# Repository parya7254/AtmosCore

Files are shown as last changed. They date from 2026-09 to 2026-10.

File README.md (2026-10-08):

# AtmosCore

AtmosCore is a smart ESP32-powered weather monitor! It consists of two modules that communicate wirelessly, one that collects weather data using sensors (which will typically be placed outside where weather data is sourced), and another that is connected to a screen and displays the data. It runs on battery that is charged by a solar panel.

# Key Features:
|Features|Model|
|-|-|
|Processor|ESPRESSIF ESP32-WROOM-32D-N8|
|Power Supply|Li-ion Battery (may change in future), chargeable by Solar Panel and by USB-C|
|Communication/Data Transfer|ESP-now|
|LDO|TPS63020DSJR buck boost|
|Battery Charger|TP4056|
|Temperature + Humidity + Pressure sensor|BME280|
|Light Sensor|BH1750FVI-TR|
|Temperature Sensors|KNTC0603/10KF3950|
|Radar Sensor|LD2140C

# Pictures of Outdoor Module!!
SCH_AtmosCore-Outdoor-Schematic_1-P1_2026-10-05
PCB_AtmosCore-Outdoor-PCB_2026-10-05
3D_AtmosCore-Outdoor-PCB_2026-10-05


# Pictures of Indoor Module!!
SCH_indoor-module_1-AtmosCore-Indoor-Schematic_2026-10-05
PCB_AtmosCore-Indoor-PCB_2026-10-05
3D_AtmosCore-Indoor-PCB_2026-10-05


## Note: This project was made with AI for researching stuff!

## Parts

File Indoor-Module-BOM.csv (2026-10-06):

No. | Quantity | Comment | Designator | Footprint | Value | Manufacturer Part | Manufacturer | Supplier Part | Supplier | LCSC Price | JLCPCB Price
1 | 5 | 100nF | C1,C2,C3,C12,C13 | C0603 | 100nF | CC0603JRX7R9BB104 | YAGEO(国巨) | C91183 | LCSC |  | 0.0032
2 | 2 | 10uF | C4,C8 | C0805 | 10uF | CL21A106KAYNNNE | SAMSUNG(三星) | C15850 | LCSC |  | 0.0098
3 | 2 | 1uF | C5,C11 | C0603 | 1uF | CL10A105KB8NNNC | SAMSUNG(三星) | C15849 | LCSC |  | 0.0022
4 | 3 | 100nF | C6,C7,C9 | C0402 | 100nF | CC0402KRX7R7BB104 | YAGEO(国巨) | C60474 | LCSC |  | 0.0008
5 | 1 | 1uF | C10 | C0402 | 1uF | TCC0402X5R105M6R3AT | CCTC(三环) | C2887021 | LCSC |  | 0.0007
6 | 1 | 22uF | C15 | C0603 | 22uF | CL10A226MP8NUNE | SAMSUNG(三星) | C86295 | LCSC |  | 0.0065
7 | 2 | SS14 | D1,D3 | SMA_L4.3-W2.6-LS5.0-RD |  | SS14 | YONGYUTAI(永裕泰) | C47147601 | LCSC |  | 0.0019
8 | 2 | Test-Point | GND,VBAT | Test-Point-0.5mm |  |  |  |  |  | 0.9351
9 | 1 | 2.54-1*14P母 | H1 | HDR-TH_14P-P2.54-V-F-1 |  | 2.54-1*14P母 | BOOMELE(博穆精密) | C52711 | LCSC |  | 0.0216
10 | 1 | YLED0603R | LED1 | LED0603-FD |  | YLED0603R | YONGYUTAI(永裕泰) | C19171390 | LCSC |  | 0.001
11 | 2 | BSS138 | Q1,Q2 | SOT-23-3_L2.9-W1.3-P1.90-LS2.4-BR-1 |  | BSS138 | KUU | C3015220 | LCSC |  | 0.003
12 | 3 | 1kΩ | R1,R2,R7 | R0402 | 1kΩ | FRC0402J102 TS | FOJAN(富捷) | C2906899 | LCSC |  | 0.0003
13 | 2 | 10kΩ | R3,R4 | R0402 | 10kΩ | FRC0402F1002TS | FOJAN(富捷) | C2906861 | LCSC |  | 0.0004
14 | 2 | 10kΩ | R5,R13 | R0603 | 10kΩ | RC0603FR-0710KL | YAGEO(国巨) | C98220 | LCSC |  | 0.0006
15 | 1 | 1.2kΩ | R6 | R0603 | 1.2kΩ | 0603WAF1201T5E | UNI-ROYAL(厚声) | C22765 | LCSC |  | 0.0006
16 | 2 | 5.1kΩ | R8,R9 | R0603 | 5.1kΩ | 0603WAF5101T5E | UNI-ROYAL(厚声) | C23186 | LCSC |  | 0.0003
17 | 2 | 4.7kΩ | R10,R11 | R0603 | 4.7kΩ | 0603WAF4701T5E | UNI-ROYAL(厚声) | C23162 | LCSC |  | 0.0005
18 | 2 | 470kΩ | R12,R14 | R0603 | 470kΩ | 0603WAF4703T5E | UNI-ROYAL(厚声) | C23178 | LCSC |  | 0.0005
19 | 1 | HLK-LD2410C-P | SM1 | SENSOR-TH_HLK-LD2410C-P |  | HLK-LD2410C-P | HI-LINK(海凌科) | C19723500 | LCSC |  | 0.8185
20 | 2 | HX 3x4x2-2P-1.6N TACTILE SWITCH | SW1,SW2 | KEY-SMD_L4.0-W3.0-LS4.9-1 |  | HX 3x4x2-2P-1.6N TACTILE SWITCH | hanxia(韩下) | C49234124 | LCSC |  | 0.0038
21 | 1 | 2.4GHz | U1 | WIFI-SMD_ESP32-WROOM-32E | 2.4GHz | ESP32-WROOM-32E-N8 | ESPRESSIF(乐鑫) | C701342 | LCSC |  | 0.6826
22 | 1 | MCP1700-3302E/TO | U2 | TO-92-3_L5.1-W4.1-P1.27-L |  | MCP1700-3302E/TO | MICROCHIP(美国微芯) | C511277 | LCSC |  | 0.1621
23 | 1 | YLED0603G | U3 | LED0603-FD |  | YLED0603G | YONGYUTAI(永裕泰) | C19273151 | LCSC |  | 0.001
24 | 1 | BME280 | U4 | LGA-8_BME280_BL |  | BME280 | Bosch(博世) | C92489 | LCSC |  | 1.1485
25 | 1 | CH340C | U5 | SOP-16_L10.0-W3.9-P1.27-LS6.0-BL |  | CH340C | WCH(南京沁恒) | C84681 | LCSC |  | 0.091
26 | 1 | K6-6277D-02A | U6 | SW-TH_TM-007-D1-A-03 |  | K6-6277D-02A | 韩国韩荣 | C5337090 | LCSC |  | 0.2208
27 | 1 | TP4056 | U7 | ESOP-8_L4.9-W3.9-P1.27-LS6.0-BL-EP |  | TP4056 | TECH PUBLIC(台舟) | C5311018 | LCSC |  | 0.0144
28 | 1 | MC-403L68-Z20 | USB1 | USB-C-SMD_MC-403L68-Z20 |  | MC-403L68-Z20 | HANBO(汉博) | C47326497 | LCSC |  | 0.0105

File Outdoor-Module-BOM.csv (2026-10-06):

No. | Quantity | Comment | Designator | Footprint | Value | Manufacturer Part | Manufacturer | Supplier Part | Supplier | LCSC Price | JLCPCB Price
1 | 2 | Test-Point | BAT+,GND | Test-Point-0.5mm |  |  |  |  |  | 0.6791
2 | 3 | 10uF | C1,C8,C19 | C0603 | 10uF | CL10A106MA8NRNC | SAMSUNG(三星) | C96446 | LCSC |  | 0.0114
3 | 5 | 100nF | C2,C3,C12,C13,C14 | C0603 | 100nF | 0603B104M500NT | FH(风华) | C286510 | LCSC |  | 0.0008
4 | 1 | 10uF | C4 | C0805 | 10uF | CL21A106KAYNNNE | SAMSUNG(三星) | C15850 | LCSC |  | 0.0098
5 | 2 | 1uF | C5,C10 | C0402 | 1uF | TCC0402X5R105M6R3AT | CCTC(三环) | C2887021 | LCSC |  | 0.0007
6 | 3 | 100nF | C6,C7,C9 | C0402 | 100nF | CC0402KRX7R7BB104 | YAGEO(国巨) | C60474 | LCSC |  | 0.0008
7 | 4 | 22uF | C11,C16,C17,C18 | C0603 | 22uF | CL10A226MP8NUNE | SAMSUNG(三星) | C86295 | LCSC |  | 0.0065
8 | 1 | 22uF | C15 | C0805 | 22uF | CL21A226MAQNNNE | SAMSUNG(三星) | C45783 | LCSC |  | 0.0332
9 | 2 | SS14 | D1,D2 | SMA_L4.3-W2.6-LS5.0-RD |  | SS14 | YONGYUTAI(永裕泰) | C47147601 | LCSC |  | 0.0019
10 | 2 | ESD5Z5V0 | D3,D4 | SOD-523_L1.2-W0.8-LS1.6-RD |  | ESD5Z5V0 | JSMSEMI(杰盛微) | C917016 | LCSC |  | 0.0041
11 | 1 | DC-005-20 | DC1 | DC-IN-TH_DC-005-20 |  | DC-005-20 | JXTCONN(聚兴泰) | C52125075 | LCSC |  | 0.0265
12 | 1 | HX PH254-01-04-Z-L11.5 straight pin header | H1 | HDR-TH_4P-HX-PH254-01-04-Z-L11.5 |  | HX PH254-01-04-Z-L11.5 straight pin header | hanxia(韩下) | C52016392 | LCSC |  | 0.005
13 | 1 | 1uH | L1 | L0603 | 1uH | FHW0603UF1R0JST | FH(风华) | C127458 | LCSC |  | 0.0069
14 | 2 | BSS138 | Q1,Q2 | SOT-23-3_L2.9-W1.3-P1.90-LS2.4-BR-1 |  | BSS138 | KUU | C3015220 | LCSC |  | 0.003
15 | 2 | 1MΩ | R1,R2 | R0603 | 1MΩ | 0603WAF1004T5E | UNI-ROYAL(厚声) | C22935 | LCSC |  | 0.0003
16 | 1 | 180kΩ | R3 | R0603 | 180kΩ | 0603WAF1803T5E | UNI-ROYAL(厚声) | C22827 | LCSC |  | 0.0003
17 | 3 | 10kΩ | R4,R5,R13 | R0603 | 10kΩ | RC0603FR-0710KL | YAGEO(国巨) | C98220 | LCSC |  | 0.0006
18 | 1 | 1.2kΩ | R6 | R0603 | 1.2kΩ | 0603WAF1201T5E | UNI-ROYAL(厚声) | C22765 | LCSC |  | 0.0006
19 | 1 | 1kΩ | R7 | R0805 | 1kΩ | 0805W8F1001T5E | UNI-ROYAL(厚声) | C17513 | LCSC |  | 0.0007
20 | 2 | 5.1kΩ | R8,R9 | R0603 | 5.1kΩ | 0603WAF5101T5E | UNI-ROYAL(厚声) | C23186 | LCSC |  | 0.0003
21 | 2 | 4.7kΩ | R10,R11 | R0603 | 4.7kΩ | 0603WAF4701T5E | UNI-ROYAL(厚声) | C23162 | LCSC |  | 0.0005
22 | 2 | 10kΩ | R12,R14 | R0402 | 10kΩ | FRC0402F1002TS | FOJAN(富捷) | C2906861 | LCSC |  | 0.0004
23 | 2 | 470kΩ | R15,R16 | R0603 | 470kΩ | 0603WAF4703T5E | UNI-ROYAL(厚声) | C23178 | LCSC |  | 0.0005
24 | 2 | HX 3x4x2-2P-1.6N TACTILE SWITCH | SW1,SW2 | KEY-SMD_L4.0-W3.0-LS4.9-1 |  | HX 3x4x2-2P-1.6N TACTILE SWITCH | hanxia(韩下) | C49234124 | LCSC |  | 0.0038
25 | 1 | 2.4GHz | U1 | WIFI-SMD_ESP32-WROOM-32E | 2.4GHz | ESP32-WROOM-32E-N8 | ESPRESSIF(乐鑫) | C701342 | LCSC |  | 0.6826
26 | 1 | BME280 | U2 | LGA-8_BME280_BL |  | BME280 | Bosch(博世) | C92489 | LCSC |  | 1.1485
27 | 1 | BH1750FVI-TR | U3 | WSOF-6_L2.6-W1.6-P0.50-TL-EP |  | BH1750FVI-TR | ROHM(罗姆) | C78960 | LCSC |  | 0.1414
28 | 1 | CH340C | U5 | SOP-16_L10.0-W3.9-P1.27-LS6.0-BL |  | CH340C | WCH(南京沁恒) | C84681 | LCSC |  | 0.091
29 | 1 | TPS63020DSJR | U6 | VSON-14_L4.0-W3.0-P0.50-BL-EP_TI_DSJ |  | TPS63020DSJR | TI(德州仪器) | C15483 | LCSC |  | 0.1367
30 | 1 | TP4056 | U7 | ESOP-8_L4.9-W3.9-P1.27-LS6.0-BL-EP |  | TP4056 | TECH PUBLIC(台舟) | C5311018 | LCSC |  | 0.0144
31 | 1 | MC-403L68-Z20 | USB1 | USB-C-SMD_MC-403L68-Z20 |  | MC-403L68-Z20 | HANBO(汉博) | C47326497 | LCSC |  | 0.0105

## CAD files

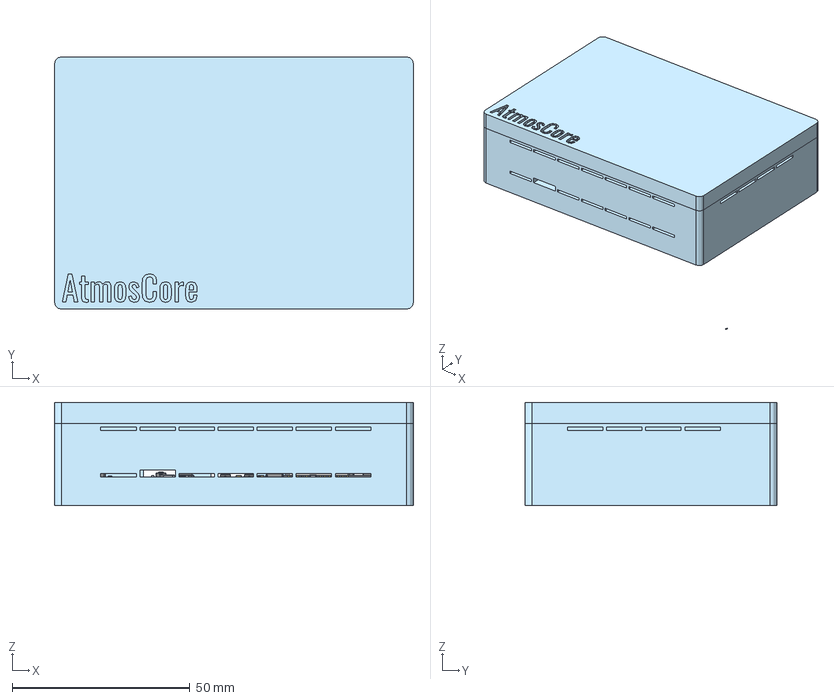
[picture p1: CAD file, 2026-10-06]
CAD/Outdoor-Module/Outdoor Module Assembly.step
101.0 x 71.0 x 67.4 mm
LGA-8_BME280_BL~LGA-8_L2.5-W2.5-H0.9-P0.65~9fjv__Í¹Ì¨ -ï¿½ï¿½ï¿½ï¿½6
SMA_L4.3-W2.6-LS5.0-RD~SMA_L4.3-W2.6-LS5.0-RD~qoYE__Í¹Ì¨ -ï¿½ï¿½ï¿½ï¿½3 x 2
C0603~C0603_L1.6-W0.8-H0.8~1LH6__Í¹Ì¨-ï¿½ ï¿½ï¿½ï¿½3 x 14
C0603~C0402_L1.0-W0.5-H0.5~J49s__Í¹Ì¨-ï¿½ ï¿½ï¿½ï¿½3 x 5
R0603~R0603~o3r0__ï¿½ï¿½ï ¿½ï¿½2 x 13
R0603~R0603~o3r0__Í¹Ì¨-ï¿½ ï¿½ï¿½ï¿½3 x 13
R0603~R0603~o3r0__Í¹Ì¨-ï¿½ ï¿½ï¿½ï¿½2 x 13
R0603~R0603~o3r0__ï¿½Ð³ï¿½-ï¿ ½ï¿½ï¿½ï¿½2 x 13
KEY-SMD_L4.0-W3.0-LS4.9-1~KEY-SMD_L4.0-W3.0-LS4.9-1~vl9t__Í¹Ì ¨-ï¿½ï¿½ï¿½ï¿½8 x 2
SOP-16_L10.0-W3.9-P1.27-LS6.0-BL~SOP-16_L9.9-W3.9-H1.5-LS6.0-P1.27~sX X8
DC-IN-TH_DC-005-20~DC-IN-TH_DC-005-20~lUyZ__ï¿½ï¿ ½ï¿½ï¿½1
DC-IN-TH_DC-005-20~DC-IN-TH_DC-005-20~lUyZ__Ô²ï¿½ ï¿½3
DC-IN-TH_DC-005-20~DC-IN-TH_DC-005-20~lUyZ__Í¹Ì¨-ï ¿½ï¿½ï¿½ï¿½5
SOD-523_L1.2-W0.8-LS1.6-RD~SOD-523_L1.2-W0.8-H0.7-LS1.6~dDVy__ï¿ ½ï¿½0.15-ï¿½ï¿½0.3-ï¿½ ï¿½0.3Ö±ï¿½ï¿½ï¿½ ï¿½ - ï¿½ï¿½ï¿½ï¿ ½-1-solid1 x 2
SOD-523_L1.2-W0.8-LS1.6-RD~SOD-523_L1.2-W0.8-H0.7-LS1.6~dDVy__ï¿ ½ï¿½0.15-ï¿½ï¿½0.3-ï¿½ ï¿½0.3Ö±ï¿½ï¿½ï¿½ ï¿½ - ï¿½ï¿½ï¿½ï¿ ½-2-solid1 x 2
SOD-523_L1.2-W0.8-LS1.6-RD~SOD-523_L1.2-W0.8-H0.7-LS1.6~dDVy__Í¹ Ì¨-ï¿½ï¿½ï¿½ï¿½ 2 x 2
WSOF-6_L2.6-W1.6-P0.50-TL-EP~WSOF-6_L1.6-W2.6-H0.8-P0.50~j2RC__Í¹ Ì¨-ï¿½ï¿½ï¿½ï¿½ 4
WSOF-6_L2.6-W1.6-P0.50-TL-EP~WSOF-6_L1.6-W2.6-H0.8-P0.50~j2RC__Í¹ Ì¨-ï¿½ï¿½ï¿½ï¿½ 2[2]
WSOF-6_L2.6-W1.6-P0.50-TL-EP~WSOF-6_L1.6-W2.6-H0.8-P0.50~j2RC__Í¹ Ì¨-ï¿½ï¿½ï¿½ï¿½ 2[3]
WSOF-6_L2.6-W1.6-P0.50-TL-EP~WSOF-6_L1.6-W2.6-H0.8-P0.50~j2RC__Í¹ Ì¨-ï¿½ï¿½ï¿½ï¿½ 2[1]
HDR-TH_4P-HX-PH254-01-04-Z-L11.5~HDR-TH_4P-HX-PH254-01-04-Z-L11.5~maJ 2__ï¿½ï¿½ï¿½ï¿½2
HDR-TH_4P-HX-PH254-01-04-Z-L11.5~HDR-TH_4P-HX-PH254-01-04-Z-L11.5~maJ 2__ï¿½ï¿½ï¿½ï¿½(ï¿ ½ï¿½ï¿½ï¿½)2[1]
HDR-TH_4P-HX-PH254-01-04-Z-L11.5~HDR-TH_4P-HX-PH254-01-04-Z-L11.5~maJ 2__Í¹Ì¨-ï¿½ï¿½ï¿½ï ¿½4
HDR-TH_4P-HX-PH254-01-04-Z-L11.5~HDR-TH_4P-HX-PH254-01-04-Z-L11.5~maJ 2__ï¿½ï¿½ï¿½ï¿½(ï¿ ½ï¿½ï¿½ï¿½)2[2]
HDR-TH_4P-HX-PH254-01-04-Z-L11.5~HDR-TH_4P-HX-PH254-01-04-Z-L11.5~maJ 2__ï¿½ï¿½ï¿½ï¿½(ï¿ ½ï¿½ï¿½ï¿½)2[3]
HDR-TH_4P-HX-PH254-01-04-Z-L11.5~HDR-TH_4P-HX-PH254-01-04-Z-L11.5~maJ 2__ï¿½ï¿½ï¿½ï¿½(ï¿ ½ï¿½ï¿½ï¿½)1[2]
HDR-TH_4P-HX-PH254-01-04-Z-L11.5~HDR-TH_4P-HX-PH254-01-04-Z-L11.5~maJ 2__ï¿½ï¿½ï¿½ï¿½(ï¿ ½ï¿½ï¿½ï¿½)1[1]
HDR-TH_4P-HX-PH254-01-04-Z-L11.5~HDR-TH_4P-HX-PH254-01-04-Z-L11.5~maJ 2__ï¿½Æ¶ï¿½ï¿½ï¿½ 1[1]
WIFI-SMD_ESP32-WROOM-32E~WIFI-SMD_L25.5-W18.0-H3.1-ESP32-WROOM-32E~HH XW__Í¹Ì¨-ï¿½ï¿½ï¿½ ï¿½4[10]
WIFI-SMD_ESP32-WROOM-32E~WIFI-SMD_L25.5-W18.0-H3.1-ESP32-WROOM-32E~HH XW__Í¹Ì¨-ï¿½ï¿½ï¿½ ï¿½4[3]
WIFI-SMD_ESP32-WROOM-32E~WIFI-SMD_L25.5-W18.0-H3.1-ESP32-WROOM-32E~HH XW__Í¹Ì¨-ï¿½ï¿½ï¿½ ï¿½4[13]
WIFI-SMD_ESP32-WROOM-32E~WIFI-SMD_L25.5-W18.0-H3.1-ESP32-WROOM-32E~HH XW__Í¹Ì¨-ï¿½ï¿½ï¿½ ï¿½3
WIFI-SMD_ESP32-WROOM-32E~WIFI-SMD_L25.5-W18.0-H3.1-ESP32-WROOM-32E~HH XW__Í¹Ì¨-ï¿½ï¿½ï¿½ ï¿½4[9]
WIFI-SMD_ESP32-WROOM-32E~WIFI-SMD_L25.5-W18.0-H3.1-ESP32-WROOM-32E~HH XW__Í¹Ì¨-ï¿½ï¿½ï¿½ ï¿½4[7]
WIFI-SMD_ESP32-WROOM-32E~WIFI-SMD_L25.5-W18.0-H3.1-ESP32-WROOM-32E~HH XW__Í¹Ì¨-ï¿½ï¿½ï¿½ ï¿½4[2]
WIFI-SMD_ESP32-WROOM-32E~WIFI-SMD_L25.5-W18.0-H3.1-ESP32-WROOM-32E~HH XW__Í¹Ì¨-ï¿½ï¿½ï¿½ ï¿½4[8]
WIFI-SMD_ESP32-WROOM-32E~WIFI-SMD_L25.5-W18.0-H3.1-ESP32-WROOM-32E~HH XW__Í¹Ì¨-ï¿½ï¿½ï¿½ ï¿½4[6]
WIFI-SMD_ESP32-WROOM-32E~WIFI-SMD_L25.5-W18.0-H3.1-ESP32-WROOM-32E~HH XW__Í¹Ì¨-ï¿½ï¿½ï¿½ ï¿½4[1]
WIFI-SMD_ESP32-WROOM-32E~WIFI-SMD_L25.5-W18.0-H3.1-ESP32-WROOM-32E~HH XW__Í¹Ì¨-ï¿½ï¿½ï¿½ ï¿½4[5]
WIFI-SMD_ESP32-WROOM-32E~WIFI-SMD_L25.5-W18.0-H3.1-ESP32-WROOM-32E~HH XW__Í¹Ì¨-ï¿½ï¿½ï¿½ ï¿½4[12]
WIFI-SMD_ESP32-WROOM-32E~WIFI-SMD_L25.5-W18.0-H3.1-ESP32-WROOM-32E~HH XW__Í¹Ì¨-ï¿½ï¿½ï¿½ ï¿½4[4]
WIFI-SMD_ESP32-WROOM-32E~WIFI-SMD_L25.5-W18.0-H3.1-ESP32-WROOM-32E~HH XW__Í¹Ì¨-ï¿½ï¿½ï¿½ ï¿½4[11]
Board~sXX8
SOT-23-3_L2.9-W1.3-P1.90-LS2.4-BR-1~SOT-23-3P_L2.9-W1.3-H1.0-LS2.4-P0. 95~eoEG__Í¹Ì¨-ï¿½ï¿½ï¿ ½ï¿½1[2] x 2
SOT-23-3_L2.9-W1.3-P1.90-LS2.4-BR-1~SOT-23-3P_L2.9-W1.3-H1.0-LS2.4-P0. 95~eoEG__Í¹Ì¨-ï¿½ï¿½ï¿ ½ï¿½1[12] x 2
SOT-23-3_L2.9-W1.3-P1.90-LS2.4-BR-1~SOT-23-3P_L2.9-W1.3-H1.0-LS2.4-P0. 95~eoEG__SOT-23-3P_L2.9-W1.3-H1.-LS2.4-P0.95ï¿½ï¿½ ï¿½ï¿½-1-solid1 x 2
SOT-23-3_L2.9-W1.3-P1.90-LS2.4-BR-1~SOT-23-3P_L2.9-W1.3-H1.0-LS2.4-P0. 95~eoEG__Í¹Ì¨-ï¿½ï¿½ï¿ ½ï¿½1[11] x 2
SOT-23-3_L2.9-W1.3-P1.90-LS2.4-BR-1~SOT-23-3P_L2.9-W1.3-H1.0-LS2.4-P0. 95~eoEG__Í¹Ì¨-ï¿½ï¿½ï¿ ½ï¿½1[9] x 2
SOT-23-3_L2.9-W1.3-P1.90-LS2.4-BR-1~SOT-23-3P_L2.9-W1.3-H1.0-LS2.4-P0. 95~eoEG__Í¹Ì¨-ï¿½ï¿½ï¿ ½ï¿½1[6] x 2
SOT-23-3_L2.9-W1.3-P1.90-LS2.4-BR-1~SOT-23-3P_L2.9-W1.3-H1.0-LS2.4-P0. 95~eoEG__Í¹Ì¨-ï¿½ï¿½ï¿ ½ï¿½1[10] x 2
SOT-23-3_L2.9-W1.3-P1.90-LS2.4-BR-1~SOT-23-3P_L2.9-W1.3-H1.0-LS2.4-P0. 95~eoEG__Í¹Ì¨-ï¿½ï¿½ï¿ ½ï¿½1[13] x 2
SOT-23-3_L2.9-W1.3-P1.90-LS2.4-BR-1~SOT-23-3P_L2.9-W1.3-H1.0-LS2.4-P0. 95~eoEG__ï¿½ï¿½0.1-ï¿½ï¿½ 0.4-ï¿½ï¿½0.6-ï¿½ï¿½0. 5ï¿½ï¿½ï¿½ï¿½-5-solid1 x 2
SOT-23-3_L2.9-W1.3-P1.90-LS2.4-BR-1~SOT-23-3P_L2.9-W1.3-H1.0-LS2.4-P0. 95~eoEG__Í¹Ì¨-ï¿½ï¿½ï¿ ½ï¿½1[1] x 2
SOT-23-3_L2.9-W1.3-P1.90-LS2.4-BR-1~SOT-23-3P_L2.9-W1.3-H1.0-LS2.4-P0. 95~eoEG__Í¹Ì¨-ï¿½ï¿½ï¿ ½ï¿½1[8] x 2
SOT-23-3_L2.9-W1.3-P1.90-LS2.4-BR-1~SOT-23-3P_L2.9-W1.3-H1.0-LS2.4-P0. 95~eoEG__Í¹Ì¨-ï¿½ï¿½ï¿ ½ï¿½1[3] x 2
SOT-23-3_L2.9-W1.3-P1.90-LS2.4-BR-1~SOT-23-3P_L2.9-W1.3-H1.0-LS2.4-P0. 95~eoEG__Í¹Ì¨-ï¿½ï¿½ï¿ ½ï¿½1[5] x 2
SOT-23-3_L2.9-W1.3-P1.90-LS2.4-BR-1~SOT-23-3P_L2.9-W1.3-H1.0-LS2.4-P0. 95~eoEG__Í¹Ì¨-ï¿½ï¿½ï¿ ½ï¿½1[7] x 2
SOT-23-3_L2.9-W1.3-P1.90-LS2.4-BR-1~SOT-23-3P_L2.9-W1.3-H1.0-LS2.4-P0. 95~eoEG__ï¿½ï¿½0.1-ï¿½ï¿½ 0.4-ï¿½ï¿½0.6-ï¿½ï¿½0. 5ï¿½ï¿½ï¿½ï¿½-7-solid1 x 2
SOT-23-3_L2.9-W1.3-P1.90-LS2.4-BR-1~SOT-23-3P_L2.9-W1.3-H1.0-LS2.4-P0. 95~eoEG__ï¿½ï¿½0.1-ï¿½ï¿½ 0.4-ï¿½ï¿½0.6-ï¿½ï¿½0. 5ï¿½ï¿½ï¿½ï¿½-1-solid1 x 2
SOT-23-3_L2.9-W1.3-P1.90-LS2.4-BR-1~SOT-23-3P_L2.9-W1.3-H1.0-LS2.4-P0. 95~eoEG__Í¹Ì¨-ï¿½ï¿½ï¿ ½ï¿½1[4] x 2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

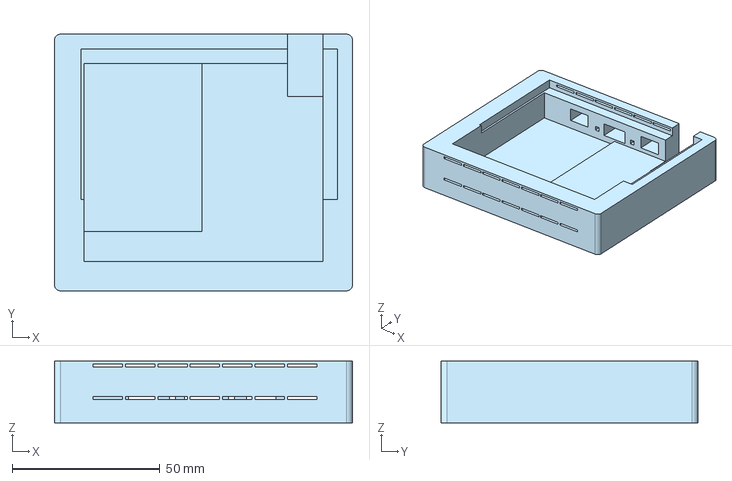
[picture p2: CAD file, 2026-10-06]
CAD/Indoor-Module/Indoor-Bottom.step
101.0 x 87.0 x 21.0 mm

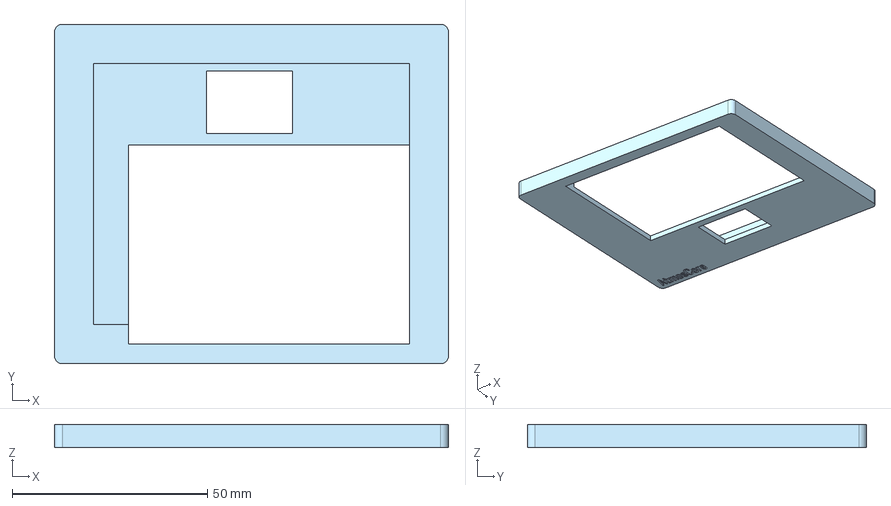
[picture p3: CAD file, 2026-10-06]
CAD/Indoor-Module/Indoor-Top.step
101.0 x 87.0 x 6.00 mm

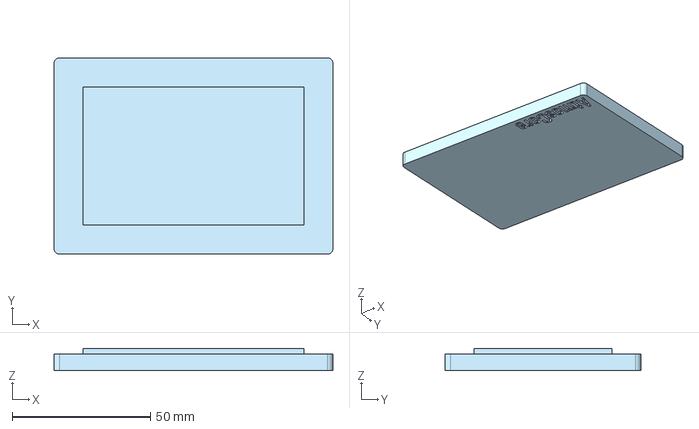
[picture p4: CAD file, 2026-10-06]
CAD/Outdoor-Module/Outdoor-Top.step
101.0 x 71.0 x 8.00 mm

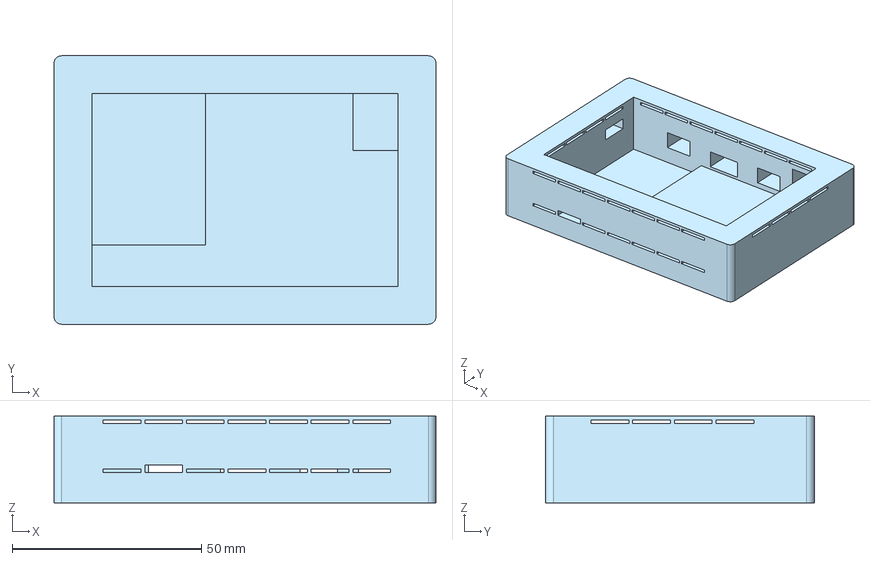
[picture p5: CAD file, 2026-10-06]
CAD/Outdoor-Module/Outdoor-Bottom.step
101.0 x 71.0 x 23.0 mm

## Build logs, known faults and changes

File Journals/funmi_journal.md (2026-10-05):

**17th and 18th September** 
So, we have our project decided on. We're gonna be working on a smart ESP32-powered weather station that contains two modules that communicate wirelessly, one that collects weather data using sensors (will typically be placed outside where weather data is sourced), and another that is connected to a screen and displays this data. It runs on battery and charged by a solar panel. More details will be added soon.

I searched, added, and wired components for our weather tracker and display system including the processor chip (espressif esp32 wroom), ldo, battery points for the solar panel and battery, and a battery charger for the battery. I also added some of the sensors for the weather. Our device will track temperature, humidity, pressure, wind speed, wind direction, rain, and light/UV.

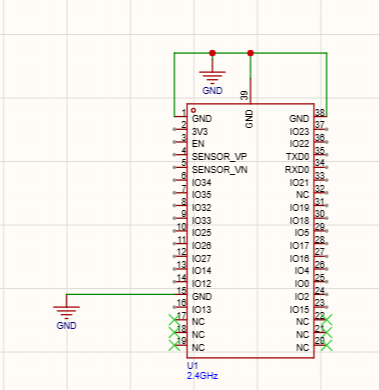
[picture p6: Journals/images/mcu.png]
mcu


power

We found suitable modules for temp, pressure, humidity and UV light, but we're still gonna finalize for wind speed, wind direction, and rain (amount of rain fall).

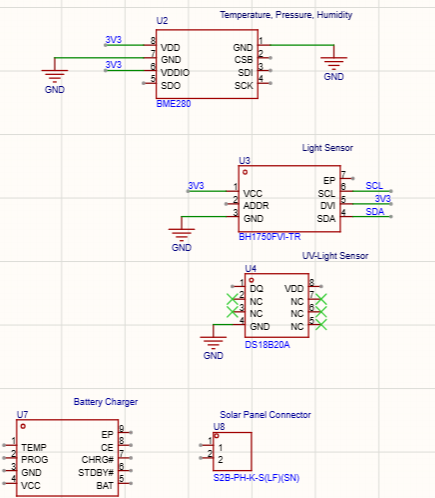
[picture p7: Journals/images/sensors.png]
sensors


Timelapse: https://lapse.hackclub.com/timelapse/0soD5C5SFuWm

---

**18th September midnight**

I started wiring the ldo. I wired input voltage, switching nodes, and power with necessary caps using the datasheet. I also wired the gpio pins on the processor.

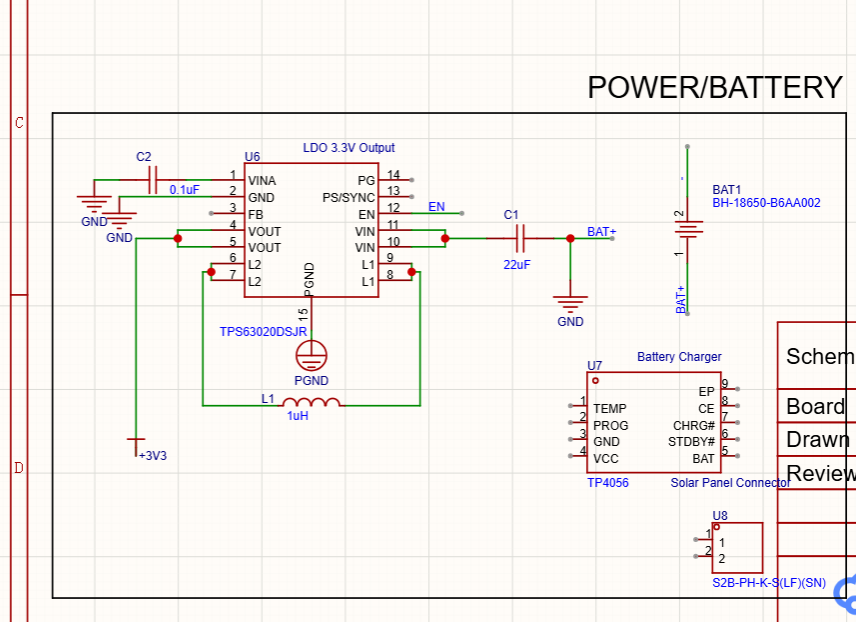
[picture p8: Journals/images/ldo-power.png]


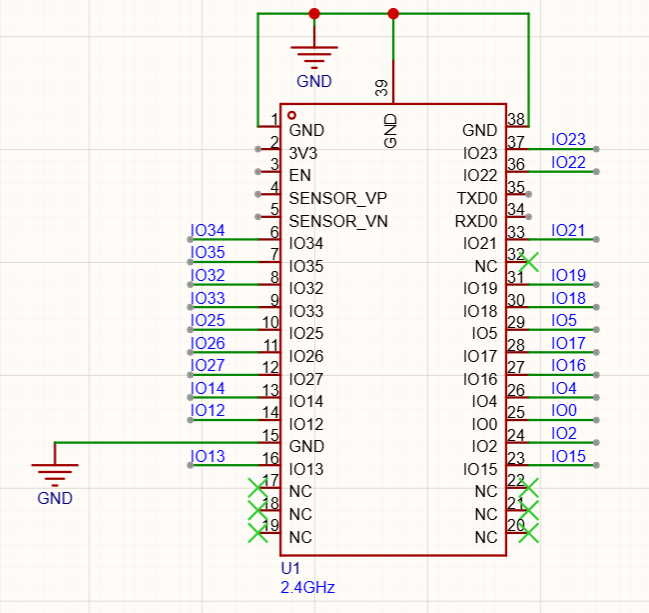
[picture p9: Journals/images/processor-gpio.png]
gpio


Timelapse: https://lapse.hackclub.com/timelapse/47Nh-5HsW0Z_

---

**19th September**

I finished wiring up the ldo. I wired up enable, power saving, and some other pins. We're gonna use the Adafruit 6V 2W solar panel that has a barrel jack connector, so I added the jack socket (or whatever its calld) that will connect to the jack of the solar panel. I also started wiring the TP4056 to the battery and the solar.

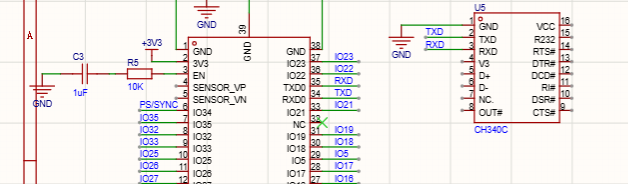
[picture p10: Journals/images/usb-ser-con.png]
usb-serial-connector


sensors

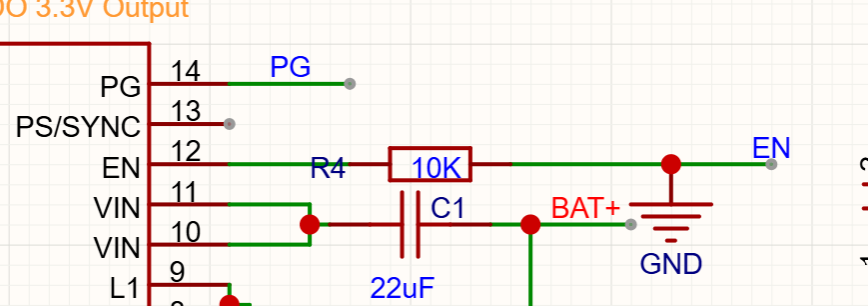
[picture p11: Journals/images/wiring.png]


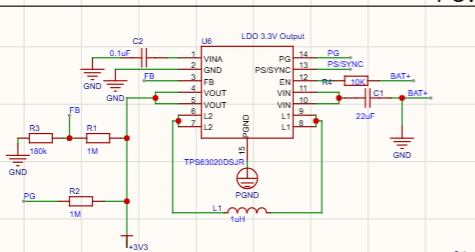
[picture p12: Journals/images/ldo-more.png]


Timelapse: https://lapse.hackclub.com/timelapse/MDIkPO2Eiles
Timelapse 2: https://lapse.hackclub.com/timelapse/ODEb5UjX_YcE

---

**19th September evening**

We decided to not connect status LEDs for the battery charger (CHRG and STDBY), but instead connect them to two separate GPIOs and have it display in our second module when the battery is charging or full. If we happen to run out of GPIOs, which I don't think we will, I'll wire both statuses to one pin.

Anyways, I finished wiring up the battery charger and fixed a lot of bugs in my wiring (for example, shorting VIN, and some other pins). I think there might still be some things I might have wired wrongly, which I'll fix tomorrow.

I also added and wired an NTC temp sensor to avoid charging the battery while it is overheated.

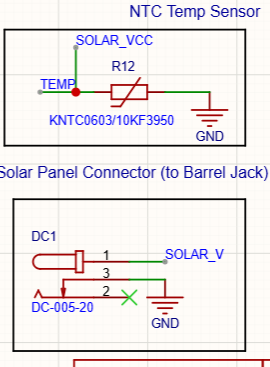
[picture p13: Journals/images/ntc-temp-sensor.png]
ntc-temp-sensor


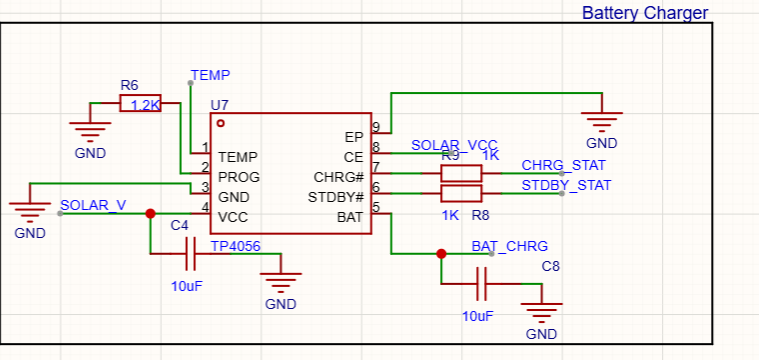
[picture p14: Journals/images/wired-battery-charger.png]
wired-batt-charger


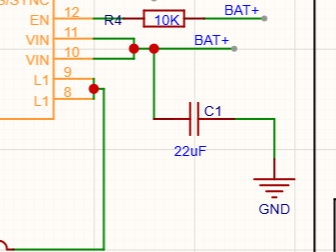
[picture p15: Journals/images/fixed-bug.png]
bug-fix


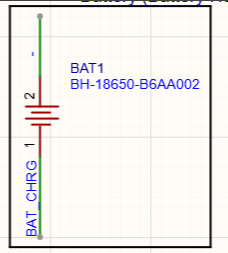
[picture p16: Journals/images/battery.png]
batt


Timelapse: https://lapse.hackclub.com/timelapse/Cc5SS9TyneUY

---

**20th September**

Rounding up wiring for the outdoor-module - I added decoupling capacitors for the battery charger and esp32..

I also added a schottky diode to prevent back charge to the solar panel. For the charging status pins, we decided we would enable pullup internally with code instead. and we removed the resistors I had added to the pins. i also fixed a couple of other wiring mistakes

Then, I began the indoor-module schematic. I added a simple LDO and testpoints for Lipo battery (so we can have a smaller device for that module) and began wiring all the components. We're still thinking of what else would be in the indoor-module, but we want a touch display and it's gonna have a menu screen, and more. We're thinking of adding an NFC tag to the outdoor module to send data to our phones when we tap it.

I also fixed some other wiring bugs in my code.

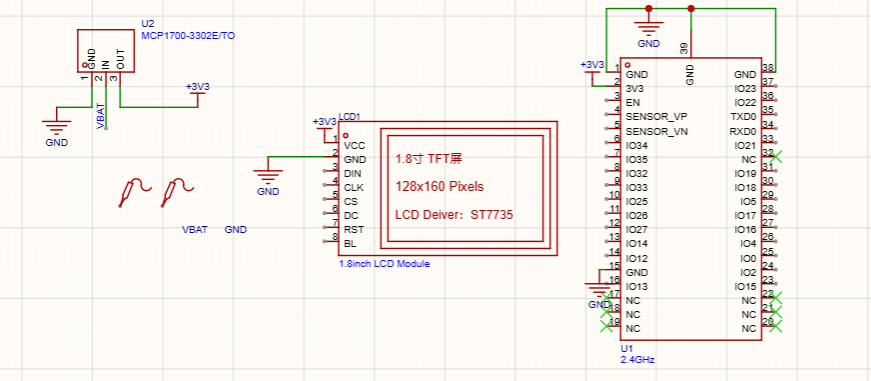
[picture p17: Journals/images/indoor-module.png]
indoor module


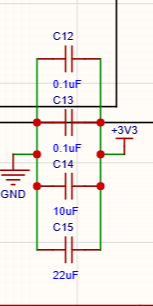
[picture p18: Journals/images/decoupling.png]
decoupling


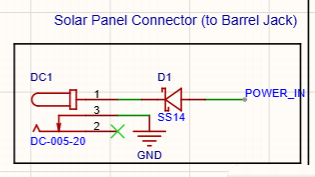
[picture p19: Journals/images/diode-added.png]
schottky


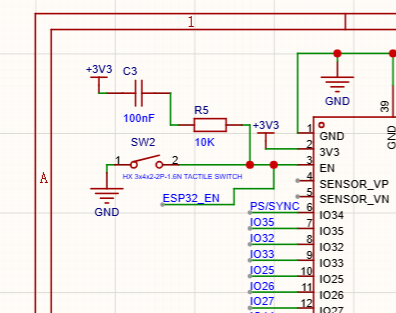
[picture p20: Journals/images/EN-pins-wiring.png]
bug fix


Timelapse: https://lapse.hackclub.com/timelapse/anTcrrIvC8c1

--
### WEEK 2
---

**25th aSeptember**( (Syncing tw)

On the first day, I cross checked our schematic, and fixed some issues with the labels. We added diodes to the power outlets/charging so that our PCB wouldn' make connections to things on the same label that don't need to be connected directly.

We decided to have another temperature module for the internal model, so it could display the difference between both.. My teammate mainly copied most of the sensor and USB-C wiring from the outdoor schematic to the indoor schematic, and changed what needed to be.

We cross-checked all our wiring, and had two of our friends sanity check our wiring. We also ran DRC and removed connections from useless GPIOs. There may still be changes in the future, but we're moving to our PCB now!

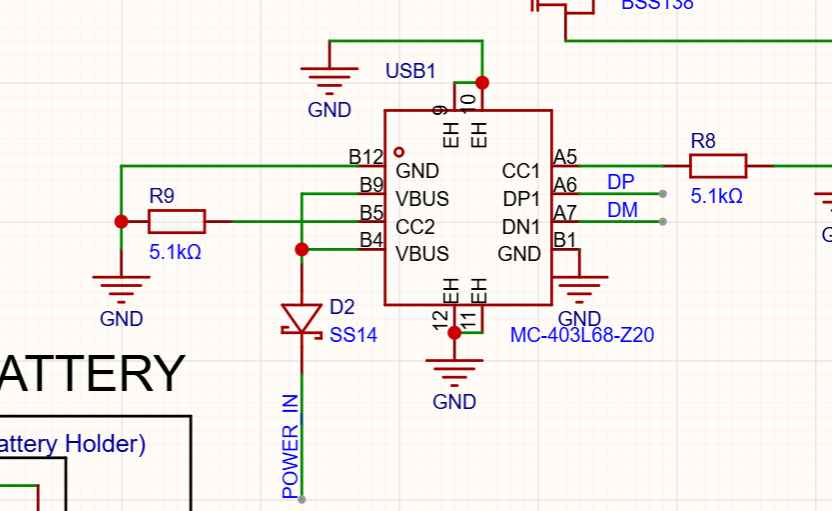
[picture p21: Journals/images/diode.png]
diode


drc

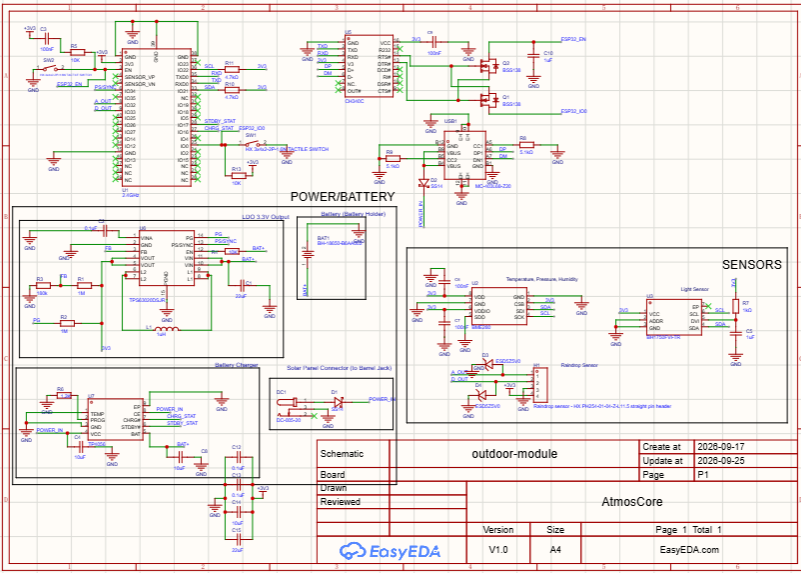
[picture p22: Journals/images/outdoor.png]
outdoor


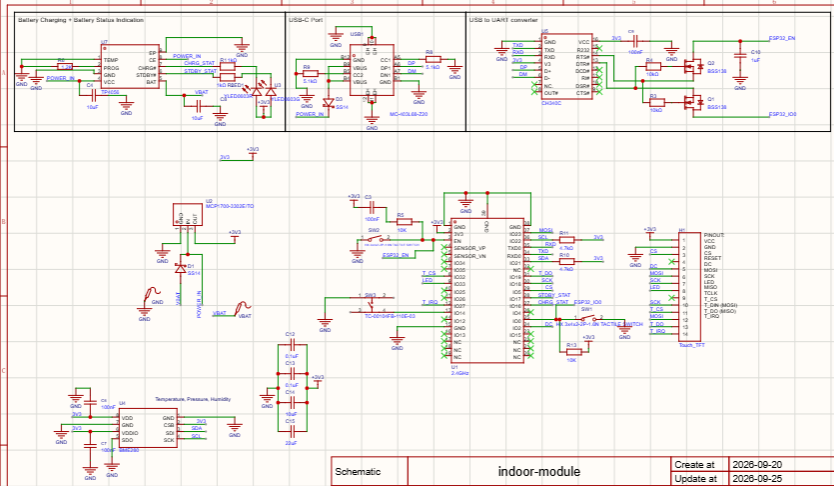
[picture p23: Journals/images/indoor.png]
indoor


Timelapse (22nd Sept): https://lapse.hackclub.com/timelapse/DbM2U7grEP55
Timelapse (25th Sept): https://lapse.hackclub.com/timelapse/LilQS_6KhUf3

---

**26th September**

We had started placing components in their places. I placed decoupling capacitors where they needed to be. I was making reference to my previous devboard for some guidance. Then I realised two huge mistakess!!! I realsied I never even opened the datasheet for the LDO I added in the internal module (maybe cuz it only had three pins) :(.. Anyways, I didn't add any input or output capacitors, which is bad. But, I later opened the datasheet and fixed that.

The second mistake I had made was the wiring of the EN pin.. It was just wrong, like wrong wrong! :(, and I fixed that asw.

I also changed the automatically assigned capacitor sizes to uniform ones 0603 and 0805 where needed, and updated the pcb! (Now that I think about it, i didn't check resistors.. maybe tmr).

My teammate added a switch to power on, and decided it would be cool to add a radar presence detector so that our device would turn on when somoen walked by or came close.. that makes 3 ways to turn it on (Touch LCD and the button asw)

After placing all the components everywhere, and fixing and ensuring correct wiring, we began routing and we've covered some grounds.. will continue tmr

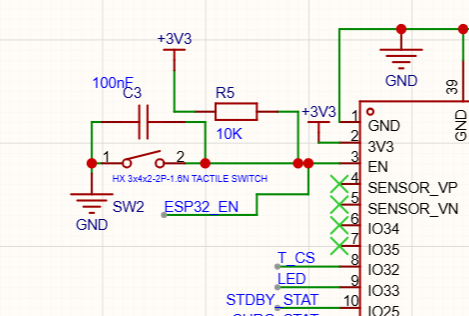
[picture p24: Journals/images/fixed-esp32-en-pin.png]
en-pin-wiring


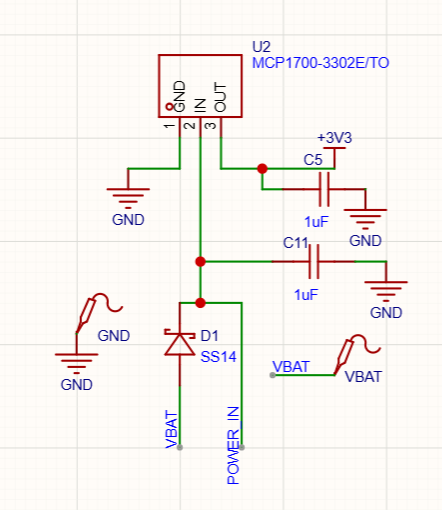
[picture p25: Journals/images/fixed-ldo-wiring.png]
ldo-wiring


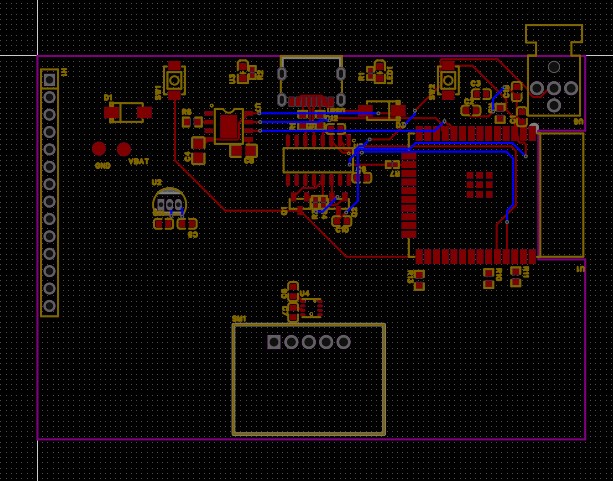
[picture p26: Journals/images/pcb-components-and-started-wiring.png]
pcb-components-and-started-wiring


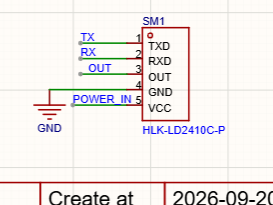
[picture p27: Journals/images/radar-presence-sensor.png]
radar-presence-sensor


Timelapse: https://lapse.hackclub.com/timelapse/GjsO2iJ3Wp_l

also this 11 mins https://lapse.hackclub.com/timelapse/RbmZFwa_v1Lu

--- 

**27th September**

We finished the indoor module PCB :)! We wired the remainign aprts form yesterday, added ground fills on both sides, and ran DRC.. Then we fixed all our errors.
Only thing that might change maybe the battery pads as they're so small.. We would also defo add some silkscreen for decor.. and info too.

After the indoor PCB, I fixed the same issues that I fixed in the indoor module yday in the outdoor module (used the same micro) and then I also hadn't added an output capacitor to the buck booster.. somehow I had missed that from the datasheet (i used the datasheet, i promise). Thankfully, I noticed.. and I also fixed the input capacitor.. the datasheet recommends 2 x 10uFs and 4 x 22uFs respectively... for the indoor, I just added 22uFs, but I realised it seems to be more effective and cancel out more noise (ig)

If anything, we'll switch them up later. 
Anyways, after fixing things up, we started placing components for the outdoor module.. We changed the FAT battery holder to testpoints/pads instead so we're gonna use those flat LiPo batteries instead (like in the indoor module). I've placed most of the main components and those that go with them, and we'll complete the remaining tomorrow)! So proud of our work so far yayayyayayay!

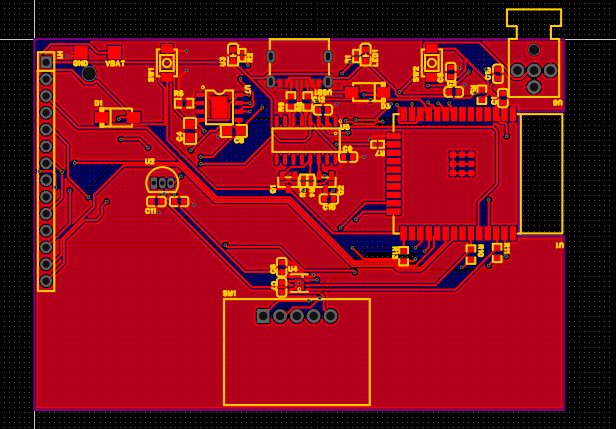
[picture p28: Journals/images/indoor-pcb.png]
finsihed-pcb


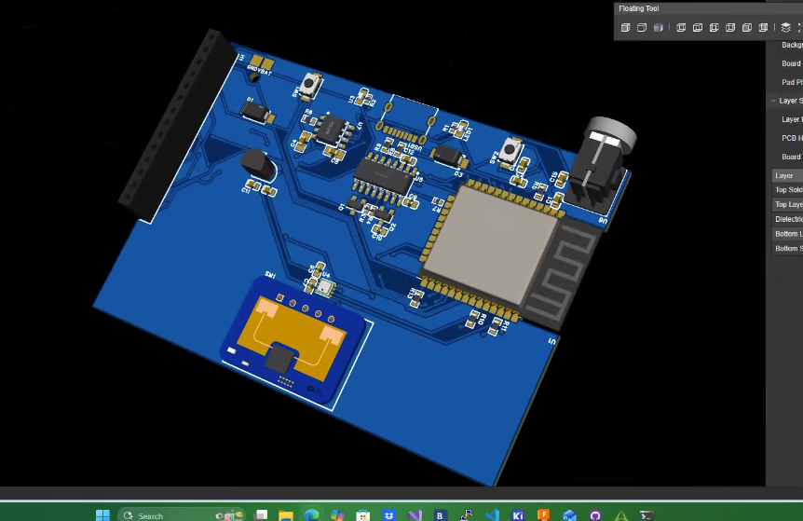
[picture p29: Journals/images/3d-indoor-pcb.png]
3d-pcb


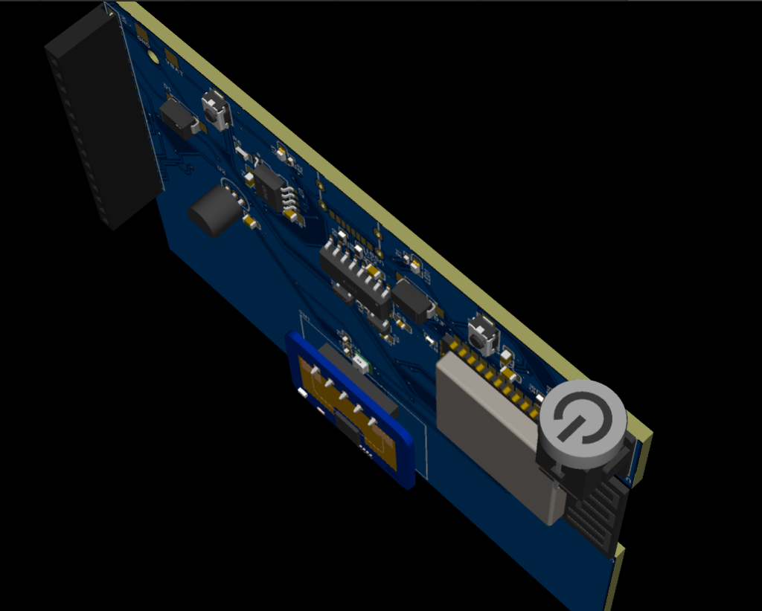
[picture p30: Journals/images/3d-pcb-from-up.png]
3d-pcb-too


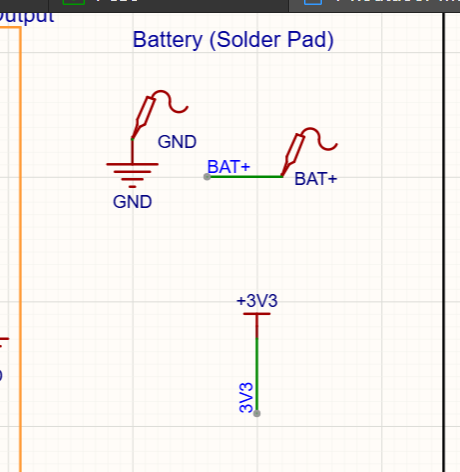
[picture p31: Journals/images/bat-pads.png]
bat-pads


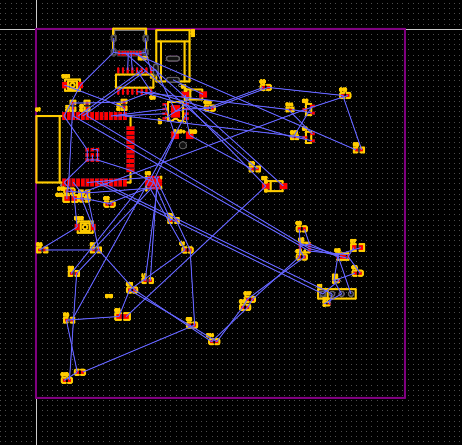
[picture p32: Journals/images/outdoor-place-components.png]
outdoor-place-components


Timelapse: https://lapse.hackclub.com/timelapse/7acM_9xCz0wH

---

### WEEK 3

**2nd October, 2026**

We finished placing components on the outdoor module, and wired it up. And of course, ground fills, DRC and all of that.. and yayya, we're done! We then remembered we needed to add battery measurement voltage dividers so I did that this morning.. and just finished this evening w my teammates help cuz I got stuck! and ofc we fixed all our errors, rebuilt ground fills and.. now we're actually done!.. we hope!

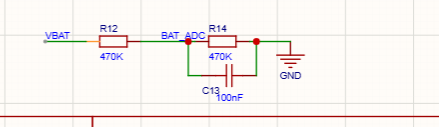
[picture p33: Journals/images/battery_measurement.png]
battery-measurement


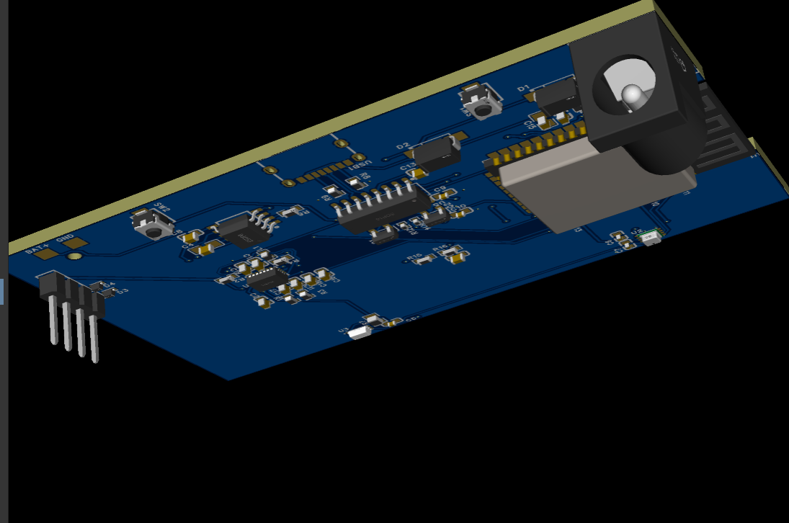
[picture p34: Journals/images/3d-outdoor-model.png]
3d-outdoor-model


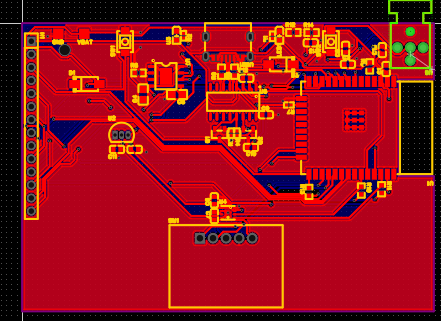
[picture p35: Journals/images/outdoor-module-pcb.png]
outdoor-module-pcb


3d-outdoor-flat

Timelapses: 
https://lapse.hackclub.com/timelapse/n3gh6F-ZVt-m

https://lapse.hackclub.com/timelapse/gxGTGI2P7w6p

https://lapse.hackclub.com/timelapse/05RpBTpiCn64

---

**2nd October evening**

We started off with CAD yesterday!! My teamtate has made the bottom and top covers (still on the top) for the indoor module! He added holes for the on-button and the usb connector! I'm using Onshape for the first time and I also kinda have always hated cad.. but i did contribute to it.. I did the fillets for the bottom aprt of the indoor module yayayya!!

We also kinda realise that we have to make the small boot and reset buttons to be accessible through the cad. we're still working on that.. but I'm gonna get started on FIRMWARE!! cuz my teammate got cad for the most part..!

indoor-cad-bottom

indoor-cad-top

Timelapse: https://lapse.hackclub.com/timelapse/77oZqxya-N3z

---

**3rd October**

So, for the CAD, I did the top layer for the indoor module! Then we realised that the module was covering the radar and it would probably not measure someone's presence. So, I increased the size of the pcb (by 10mm) and moved the radar to the bottom of it!! Then we increased the size of the cad as well .. both top and bottom!!

we did the assemlbly and put aligned all the aprts together! Then my teammate branded it this morning, he had also added holes for the OLED to show and all. now we've added holes for ventilation or to reduce overheating in tboth modules.,

ATMOS CORE CAD IS FINISHED( also we call it iBrick.. cuz it looks like a brick sth Apple will make)!

indoor-cad-complete
outdoor-module
outdoor-top
outdoor-bottom
increased-length-outdoor

Timelapse: https://lapse.hackclub.com/timelapse/xjRKseYRGz7s

---

**October 4th**
I started writing the previous journal before but didn't commit!

Oke, We're done! Like done done!

For the code, we were first using espidf, then we switched to arduino.. cuz espidf was so low_level and we would have to be writing almost bare metal code!

I know both c and cpp so it wasn't tooo bad, but I had to do reserach of the libraries.. and I copied some default code, created the data structures for our code and wrote the header and implementation files for reaidng and implementing the functions. I asl did the pin mapping before this for both the indoor and outdoor modules! Our code is functional and prints to a serial monitor. There's minor changes to be made but only for when we do the actual assembly and are able to test the code!

I also installed platformio on my vscode and ran the file in the early stages to make sure it ran and worked! and it did, which is why we have those build files.. you can ignore those (the cmake, the gitignore, the build and components folder were all made by platform io, so plz ignore them!)

My teammate made some minor changes to the cad asw!! So, now we're completely done w AtmosCore! if we decide to build/assemble this masterpiece :), we will defo!!

indoor-cad-complete
outdoor-module

ATMOSCORE (AKA IBRICK!!) by za wonderful Funmi and Arya!!!

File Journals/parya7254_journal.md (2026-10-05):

# 9/17/2026 Made new project and started working on the schematic!! (1hr)

Today, I started working on this project which is going to be a ESP31-powered weather station with Funmi! Starting off, we brainstormed how our weather station will be and what parts/sensors it will have. Then, I made a new EasyEDA team and invited Funmi to it so that we could collaborate on the PCB and schematic. Moving on to the schematic, I first did the ESP32 where I did have some trouble on finding the perfect module. I was looking for an ESP32 module, not the bare chip as the module had the flash chip and all of the other essentials along with the WiFi+BT antenna which is very crucial as designing that by ourselves would be quite troublesome and maybe problematic. While searching for a good ESP32 module, I could not find one and I got many bare chips. I tried many different keywords but did not get results that satisfied my request. But, after some while of searching, I finally stumbled upon a module that satisfied my requirements. I then went on searching for a BME280 temperature, humidity, and pressure sensor which was not hard, and the same could be said for the BH1750 light sensor. But, when it came to the VEML6075, the IC was not in stock, and I could not find and alternatives to it as of now. I will continue working on finding the rest of the parts needed and hopefully I get done with finding all of the parts needed and put them in the schematic by the end of the next time that I work on this.

Lapse: https://lapse.hackclub.com/timelapse/F5m8yYxM26DT



# 9/18/2026 Read datasheets + wired a little power!! (2hrs)

Today, I started off with wiring some of the things that were also on the schematic. Me and Funmi also did some searching for an LDO/some sort of power regulator for 3.3V. I also added a CH340 to the schematic as well because we will need a way to communicate with our ESP32 and program it over a USB port. The CH340 will convert USB signals to serial signals so that the ESP32 can properly communicate with our computer for debugging and coding. I also started wiring the power pins for the sensors as well. I managed to wire all of the needed power pins for the BME280 and then moved on to the ambient light sensor. This was a bit more troublesome as it had some sort of special rule for one of its pins. I unfortunately did not have enough time to finish wiring the power pins for everything, but I did still make some progress in the end! And also, all of this research will be important for the proper functionality of our project as well. I also thought of an idea that was about using the schematic for the modules by Adafruit that use the same sensor as Adafruit makes everything open source. I thought about this at the end of today's work session so I will try to not forget about this the next time that I work on this.

Lapse: https://lapse.hackclub.com/timelapse/n_8TG-TNRAbT



# 9/19/2026 Finished wiring sensors! (2hrs)

Today, I managed to lock in enough and finish wiring all of the sensors. The reason that this took so long was because I had to go through the datasheet and confirm the correct way to do things. I have also never worked with a bare chip and I2C before so that was a bit problematic since I did not know about pull up resistors on I2C lines. I used 4.7k resistors on each I2C line since that was the recommended amount from looking it up and then pulled the resistor up. But I managed to learn about them today! I did use some example schematics from Adafruit's modules that use the same chip for reference to properly wiring the chip! I also had to set some pins to high or low to make sure that they have the proper address for I2C. Me and Funmi also discussed some plans for our project and its indoor and outdoor module as well.

Lapse: https://lapse.hackclub.com/timelapse/fbDPuQSLvLiT



# 9/20/2026 Finished wiring CH340C to ESP32 and also added a USB-C port!! (3hrs)

Today, I managed to finish wiring the CH340C, which is a USB to serial converter, to the ESP32! I also added and almost finished the USB-C port, all that I have left to do is wire the CC pins along with the VBUS. I did take a lot of time today as I got stuck on wiring the CH340C to the ESP32, the RX and TX was not too hard, but the part that automatically reset and put the ESP32 into the code upload mode every time code needs to be uploaded to the board. I got stuck on this because the wiring was pretty weird and there was a weird symbol on the reference schematic that I looked up. All of the reference schematic for the CH340C to the ESP32 had the same weird thing and then I later learned that they were a thing called MOSFETS, which work similarly to a transistor, or that's my understanding on this. And the signal and gate pins were also wired very weirdly, and I really got confused during this part. After stressfully wiring that together, I worked on the USB C port and finding a good port that had less pins but still supported data transfer. I got the data pins with the GND pins wired, but I still have to work on the VBUS and CC1 and CC2 pins. I also did some research on the TP4056 and its pins.

Lapse: https://lapse.hackclub.com/timelapse/sECMAntu1_vI



# 9/21/2026 Finished USB-C port + started working on indoor module!! (1hr)

Today, I did some research on the USB-C CC pins and learnt that they are pins that can detect the orientation of the cable plugged into it and that they are also crucial to getting power from USB-C and also very important in USB PD, which can negotiate higher amps and voltages. I did some research on these pins, although I did not find the results that I needed initially, after some more searching and rewording my question, I found an answer, I also hunted for another source to confirm the correct values. It turned out that I needed to out a 5.1K pulldown resistor on both of the CC pins so that they can even receive power in the first place, I do not need USB PD in this as this is very low power and I just need USB power in general. After I finished that, I moved on to the indoor module, as we thought the outdoor module's schematic was finished! We decided to use the same ESP32 chip on the indoor module, and I went to find a display. We decided to go for a touchscreen TFT, and I did spend some time searching for ones that were decently priced. We were going to do a bigger screen, but it was not worth the very large price difference, even though they were the same resolution, and we decided to stick with 2.8 inches. I managed to also find a good header pin footprint, and we will not get this assembled by PCBA and solder this by hand. I had to stop after I added the footprint for today, and I will continue to work on the TFT the next time that I work on this project.

Lapse: https://lapse.hackclub.com/timelapse/WTt2GvQR11WG




# 9/22/2026 Finished the display, CH340C, and almost the USB-C port on the indoor module!! (1.2hr)

Today, I moved further on to the indoor module and started off with the display. I first manually went through and edited all of the pins of the symbol to match the pinout of the LCD in order. After getting that, I found a guide online that was for ILI9341 touch displays, which is what we are using for the touchscreen indoor display. I wired the display together to the ESP32, as the guide said, and I left the MISO for the display unconnected so that it would not interfere with the MISO for the touch chip on the display, and I also left the RST pin on the chip unconnected since that was optional, and I did not think that pin would be necessary. But I did connect T_IRQ to the ESP32 even though it was optional because I felt like that pin could be used for some features in the code. I also connected the backlight pin of the LCD to a GPIO rather than 3.3V so that I can have a variable backlight, maybe this could be a feature that the T_IRQ pin could be used for to reactivate the display when it goes inactive after some time. I also copied over the CH340C and the USB-C port from the outdoor module's schematic so that we have a way to program this board from USB. I also did a quick check on the pins to make sure that all the pins were properly connected, but I may do a deeper confirmation on each thing that I imported from the outdoor module's schematic to make sure that I did not miss anything the next time I work on this project.

Lapse: https://lapse.hackclub.com/timelapse/J-Z-gBlOViqR



# 9/23/2026 Finished USB-C port and added battery charging module and also confirmed wiring!! (0.5hrs)

Today, I confirmed all of the wiring of all the things that I pasted from the outdoor module's schematic to the one for the indoor module! I also managed to add a TP4056 which is a battery charging module to the schematic and finish wiring it! I also managed to complete the wiring for the USB-C port, but I think that we may have to change some power in pins around. But for today, I directly connected the power from the USB-C port to the TP4056 as it can support a power range from 4-8V. I did organize the parts into specific boxes so that it would be easy to tell what was what and also make our schematic look neater and more organized. I also made some changes to some net names and moved some wiring around since I think that there is no need for a solar panel on the indoor module. I also added some charging LEDs to the CHRG and STBY pins on the charging IC because it would make more sense to have charging LEDs for an indoor door module rather than an outdoor module where it would be barely visible and not so useful. I might revise power, if nessesary, the next time that I work on this project.

Lapse: https://lapse.hackclub.com/timelapse/oKhIT1_g9Br1



# 9/24/2026 Finished all of the schematics!! (1.1hrs)

Today, we managed to finish both of the indoor and outdoor schematics! We continued to work on the indoor and we decided to add a temperature/pressure/humidity sensor to it to view information of the indoor environment at a glance! I check over its wiring to confirm everything and it was a good thing I did because I saw a pin that was supposed to be connected to something but was not. I read over the datasheet for the SDO pin on the BME280 and learnt that it was for setting the I2C address when it was in I2C mode! I then fixed the wiring on both the indoor and outdoor schematics. I also confirmed all of the wiring for the indoor module's schematic and then I did notice some mistakes, so I fixed them and this is good because they may have ruined our PCB! Now, for the outdoor schematic, I went over and skimmed over its wiring. It was also a good thing that I did because there were also some issues with wiring on that schematic as well. I fixed the power out for the USB because it was supposed to go to the main power in for the entire board. I also added diodes to both the power from the battery and the USB-C port as well because I did not want any power backflowing and potentially ruining the battery and/or the device that is providing power for USB.

Lapse: https://lapse.hackclub.com/timelapse/r-nnZGUj-LDX

SCH_outdoor-module_1-P1_2026-09-24
SCH_indoor-module_1-P1_2026-09-24

# 9/25/2026 Started PCB for indoor module + fixed some mistakes!! (2hrs)

Today, I managed to start working on the actual PCB for the indoor module! But before doing that, we decided to start planning the case, so that we know how we should design the actual PCB. We currently have a case in the shape of a triangular prism planned. The back of it will have the charging port, along with the reset and boot buttons, and also the battery status LEDs. We also added a power button on the top of the case. The case design may change later on though. Moving on to the PCB, I started placing the components around and finding a good order. While placing the components though, I did find out that I had wired some of the things to the CH340C incorrectly and went to fix them. I rewired the entire part than automatically set the ESP32 into boot mode. After fixing that, I continued on to the PCB, where I continued to keep placing the parts. I have forgotten to update the CH340C in the outdoor module's schematic and hope to do so the next time that I work on this project. After getting most of the core parts placed, I looked at some references, like the CYD (cheap yellow display) and saw that the PCB had a cutout where the ESP32's antenna stuck out, so I edited the shape of the outline to do the same. I also used an ESP32 board that I had laying around for getting some reference for placing my parts. I should be able to finish all of the component placements for the indoor module's PCB by the end of the next time that I work on this project!

Lapse: https://lapse.hackclub.com/timelapse/2hj70kKTxeaL

Case-Prototype-Drawing


# 9/26/2026 Finished PCB parts placement + added radar sensor + updated planning for case!! (2.7hrs)

Today, I managed to finish placing components on the PCB, add a radar module to the indoor module for human detection, and also update the design of the case! I first started off with continuing to place the components on the PCB and then I got an idea on a different type of enclosure for the device, instead of doing a triangular prism, I decided to do a case like a tablet which would make it more portable. And if the user wants to keep it standing on a desk, I also planned a stand for it. Since the display will be parallel to the PCB in this enclosure, the USB-C data/charging port will be on the top. I also changed the power button into a button that lights up! The button is a bit big so I will have to design the case around that, but the coolest part is that the button has a built in LED! I connected the LED to a GPIO so that I can have the ESP32 display statuses on it. After I finished redesigning the case, though, I continued to work on the PCB and got the idea of putting a radar sensor in it. I got this idea from those round Google Nest smart thermostats as they detect people and then the display automatically lights up when it does. I wanted to apply a similar concept to that. So, I added an inexpensive LD2410C human detection radar module to it. This module did make the case bigger and slightly bulkier, but the feature will be very useful later on as many users might keep it on a desk more than they carry it around. I think that I am finally done with the schematic for the indoor module and don't have any more things to add to it. I then finished up the placement for everything and then moved on to wiring! I managed to get some wiring done and finished the wiring for the USB-C port and the CH340C USB-to-Serial converter!

Lapse: https://lapse.hackclub.com/timelapse/niB1LtsmsYx9


Case-Prototype-Drawing-AtmosCore-Final

# 9/27/2026 Finished PCB for indoor module!! (2 hrs)

Today, I continued with wiring the PCB for the indoor module and managed to finish it! I worked on wiring the things from the ESP32 to the components and finished that. I did not wire any GND because I was going to do a ground fill for that. After I finished wiring the things from the ESP32 to the components, I helped Funmi with wiring and then I added a ground fill zone on both the front and back layers of the PCB. We than ran DRC and then we got a lot of errors, and most of them were for isolated areas from the main ground pour which prevented those components from being connected to GND. We had to manually move components around and then connect the GND zone to other GND zones. But we managed to get through this and finished the PCB for the indoor module. I also decided to make the battery solder pad bigger, but I still think that it is pretty small, but it is big enough to solder. And I also added a hole to the PCB because EasyEDA was being buggy and did not allow me to put the solder pads on the back side of the PCB, where the battery will be. We did move on to the PCB for the outdoor module, and I did correct the CH340C in its schematic, but we were not managed to get work done on it because there were some things that needed to be fixed. 





Lapse: https://lapse.hackclub.com/timelapse/y9PWhYpRvxX6

# 9/28/2026 Noticed a fatal mistake with indoor module's PCB + started layout for outdoor module's PCB!! (45 mins)

Today, I managed to start with the layout for the outdoor module's PCB! But I also was checking through the PCB for the indoor module, and I realized a fatal error, the footprint for the CH340C was flipped and all of the pins were reversed. I first started with laying out the PCB for the outdoor module and I was using the indoor module's PCB as a reference for a good layout to make things easier. But which I was on the CH340C, I was looking at the placement of some things, and I saw that the pins for the CH340C were horizontally mirrored. I checked through the symbol and footprint given for the part on the LCSC website, and I confirmed that it was wrong. I did not have time to confirm this design error with any other components, but I will try to work on this the next time that I work on this project. We will have to unroute many things and then fix the symbol and then rewire those things back, hopefully it won't be too hard and take too much time from working on the outdoor module's PCB. 

Lapse: https://lapse.hackclub.com/timelapse/Bsg8yYXhbAp2



# 9/29/2026 Continued with placement of parts on the PCB for the outdoor module!! (1hr 15 mins)

Today, I looked back at the indoor PCB to see why the CH340C was reversed, and then I zoomed out and then saw that the biggest component, the ESP32, was on the other side of the PCB and also reversed. I then realized that this was a viewing error and not a design error and looked through the buttons in the top toolbar of the PCB editor. I then saw that one of the buttons were highlighted and then clicked it which returned everything else to normal. Now, moving on to the PCB for the outdoor module, I continued with the placement of parts on it. We also discussed in a Slack Huddle on how we should place the parts and stuff on the PCB, and we also discussed a big issue, waterproofing. The thing is, it can rain outside, and the PCB is well, not exactly waterproof/water resistant enough to handle that. We also had to expose the sensors as well to the open air, which are also not waterproof. This might be a big issue to think about while designing the case for the outdoor module. We will have to expose the sensors without exposing them to the rain. We will discuss more about that when the time comes to design the case for the outdoor module. Other than that, I managed to get a good chunck of caoacitors placed and maybe one or two resistors. The placement should be finished or almost done by the end of the next time that we work on this.

Lapse: https://lapse.hackclub.com/timelapse/pnjjUVFZs-LN



# 9/30/2026 Finished PCB components placement + started wiring components!! (1hr 15 mins)

Today, I managed to complete the placements of the parts on the PCB and also start wiring some things! I continued with the capacitors and did everything other than the decoupling ones. I also finished the placement of all of the resistors on the PCB. I also went back and crossed check the placement of the capacitor or resistor with the placement of them in the schematic. I then continued with placing the decoupling capacitors where I ran into the problem of not knowing where to put them on the PCB. I got some guidance from my teammate, Funmi, who told me to put 100nF and 22uF decoupling capacitors near the ESP32's 3V3 pin. We then realized that there was an extra 10uF decoupling capacitor and then removed it. And then, I moved on to wiring the components on the PCB. I started with wiring the areas that I thought were the hardest and cluttered, like the LDO. After I completed wiring the LDO, I moved on to wiring some power pins and connecting some things to the ESP32. We should be able to get most of the wiring done by the end of the next time that we work on this project!

Lapse: https://lapse.hackclub.com/timelapse/NGEkKWjFGjx7



# 10/1/2026 Finished PCB for the outdoor module!! (45 mins)

Today, I continued and finished the wiring of the outdoor PCB! We also added a ground fill. But we managed to complete the whole PCB and everything for it! We first continued with wiring the PCB and then ran DRC for it. We then corrected the errors of the DRC. You may notice that we did not do any GND, and the reason for that was that we were doing a ground fill. After correcting the DRC errors for non-GND things, we moved on to the ground fill. The ground fill was not perfect and there were unconnected zones/islands. We then corrected them by connecting them to other things connected to a zone with the GND source, and I went to the 3D viewer for the PCB. I then saw that there was PCB under the antenna of the ESP32 module, so I changed the outline of the rectangle on the layer for the board outline. I then corrected the outline by making it to around the antenna and then confirmed everything else quickly and now we are done with the PCB designing part of the project!

UPDATE: Funmi is going to add battery percentage sensing today on both the indoor and outdoor module's PCB when I am gone so the PCB designing part of the project is not 100% completely done.

Lapse: https://lapse.hackclub.com/timelapse/XhcEM4rOD5U5




# 10/2/2026 Started CAD for indoor module!! (2 hrs)

Today, I started working on the CAD for the indoor module! I first started with making a new Onshape project as it supported sharing with team members and working with live updates and was also browser-based. I did have some trouble while trying to set up the collaborator thing, but I managed to do it. I also got my teammate, Funmi, to create an account for Onshape. After getting that ready, I worked on designing the bottom part of the case while Funmi worked on fixing some problems/errors in the PCB. I fist made a sketch that had one rectangle that was 1 millimeter bigger on each side and then another rectangle that was 10mm bigger on each side than the first rectangle. I then went back and forth from and to the PCB to get the distances and everything needed for the case. I also did look over some datasheets/blueprints for the power button to get the proper dimensions in place for this. Funmi then also added some filets on the corners for a cleaner asthetic. You may notice that the top of the case (where the USB-C port and the power button is) has no filets and this is because I want to keep a nice balanced, minimalistic, simple, and very Apple-like design for the case. Not having any rounded properties on the top just gave Apple-product vibes so I decided to go with that. I will continue with finishing up the case during the next time that we work on this project.

Lapse: https://lapse.hackclub.com/timelapse/pQ9YjL-gYnOz



# 10/3/2026 Finished CAD for the indoor module + also assembled it!! (3 hrs 45 mins)

Today, I continued with the CAD for the indoor module and managed to finish it and also assemble it! I completed the basic bottom part of the case and imported the PCB into an assembly along with the bottom case. I looked at how things looked and went back and forth making changes to make it perfect with everything on the PCB! I had quite some trouble with perfectly aligning the PCB to the case, and it had to be perfect so that I could make perfect adjustments. I then finished adjusting all of the holes and then added the TFT display to the assembly after I went hunting for a model that had the proper display size. I then realized that the display was quite a bit bigger than the header pins, so I had to make some space by cutting some of the case. I then realized that the TFT display was interfering with the radar module, so Funmi went back to the PCB for the indoor module and then moved the radar module down by 10 mm. Then we did the top part of the case, and I went back and forth from the assembly to the part for the top part of the case to make some precise adjustments. I then had to reimport and reposition everything perfectly, but this time the radar was safe! I think that now we are officially done with the CAD and assembly for the indoor module! I will hopefully continue with the CAD by working on the CAD for the outdoor module during the next time that I work on this.

Lapse: https://lapse.hackclub.com/timelapse/v99ebhN0Yk2b







# 10/4/2026 Finished Project!! (2hrs 15 mins)

Today, started and finished the CAD for the outdoor module and Funmi worked on the code while I helped a little bit with my little knowledge of code! And we managed to finish the project today! I started off with a rough outline of the bottom case, while also going back to the PCB to get some reference measurements for them. I then did the same thing that I did for the CAD of the indoor module, assemble it and then go back and forth and fine tuning it. I then repeated did that. I then realized that the sensors would have to be exposed to the outside in one way so I added vent holes on each side so that we could get decently accurate readings while having a better water resistance than rather not having a lid on the top. I also made another row of holes on the front of the case so that light would flow in, and also so that there would be more air and ventilation for the BME280. I also added some vent holes to the indoor module as well since that also has a sensor in it. I then worked on the lid for the outdoor moduke and then I realized that I had forgotten to brand it! So, I picked a good font and branded both tops of the cases! And for the connectivity of the top part of the case to the bottom, I decided that I will have to do that in a sliced, by assembling those two pieces together and then preforming a cut while also adding connectors. I tested that out with 2 separate cubes, and it worked and I could not do that in Onshape because they did not have a button to make connectors between two parts.

Lapse: https://lapse.hackclub.com/timelapse/RVo0fO54Z9kG







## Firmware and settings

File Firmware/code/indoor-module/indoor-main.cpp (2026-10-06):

#include <Arduino.h>
#include <Wire.h>
#include <esp_now.h>
#include <WiFi.h>

#include <Adafruit_BME280.h>

#include "config.h"
#include "data_n_func.h"


Adafruit_BME280 bme280;
IndoorData indoorValues;
OutdoorData outdoorValues;

uint8_t outdoorAddress[] = { /* ESP32 ADDRESS */ };


//the void on data recv function was copied from docs.. same as the datasend in the other file

void onDataRecv(const esp_now_recv_info_t * recv_info, const uint8_t *data, int len) {
  if (len == sizeof(OutdoorData)){
    memcpy(&incomingData, data, sizeof(incomingData));
    Serial.print("Outdoor data received: ");
  }
  else
    Serial.println("wrong data size received");


void setup(){
    Serial.begin(115200);
    delay(1000)

    Serial.println("AtmosCore Indoor!!");


    analogReadResolution(12);
    Wire.begin(I2C_SDA_PIN, I2C_SCL_PIN);

    if (!bme280.begin(0x76))
      Serial.println("BME280 initialization failed!");
    else
      Serial.println("BME280 initialized successfully!");

    WiFi.mode(WIFI_STA);

    if (esp_now_init() != ESP_OK){
        Serial.println("ESP-NOW initialization failed!");
        return;
    }

    esp_now_register_recv_cb(OnDataRecv);

    Serial.println("ESP-NOW ready!");
}




void loop() {
  indoorValues.temperature = bme280.readTemperature();
  indoorValues.humidity = bme280.readHumidity();
  indoorValues.pressure = bme280.readPressure() / 100.0F;

  indoorValues.bat_volt = analogReadMilliVolts(BATTERY_ADC) * 2.0F / 1000.0F;

  Serial.println("----- INDOOR -----");
  Serial.println();
  Serial.print("Temperature: ");
  Serial.print(indoorValues.temperature);
  Serial.println(" °C");

  Serial.print("Humidity: ");
  Serial.print(indoorValues.humidity);
  Serial.println(" %");

  Serial.print("Pressure: ");
  Serial.print(indoorValues.pressure);
  Serial.println(" hPa");

  Serial.print("Battery: ");
  Serial.print(indoorValues.bat_volt);
  Serial.println(" V");


  Serial.println();
  Serial.println("----- OUTDOOR -----");

  Serial.print("Temperature: ");
  Serial.print(outdoorValues.temperature);
  Serial.println(" °C");

  Serial.print("Humidity: ");
  Serial.print(outdoorValues.humidity);
  Serial.println(" %");

  Serial.print("Pressure: ");
  Serial.print(outdoorValues.pressure);
  Serial.println(" hPa");

  Serial.print("Light: ");
  Serial.print(outdoorValues.light_lux);
  Serial.println(" lux");

  Serial.print("Rain: ");

  if (outdoorValues.isRaining)
  {
      Serial.println("YES");
  }
  else
  {
      Serial.println("NO");
  }

  Serial.print("Outdoor Battery: ");
  Serial.print(outdoorValues.bat_volt);
  Serial.println(" V");


  delay(5000);
}

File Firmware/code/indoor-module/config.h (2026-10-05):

#pragma once

#define BATTERY_ADC_PIN 35
#define I2C_SDA_PIN 21
#define I2C_SCL_PIN 22

#define BME280_ADDR 0x76
#define BH1750_ADDR 0x23

#define LED_PIN 33
#define PWR_LED_PIN 13

#define CHRG_STAT_PIN 26
#define STDBY_STAT_PIN 25

//TFT
#define TFT_MOSI_PIN 23
#define TFT_SCLK_PIN 18
#define TFT_CS_PIN 5
#define TFT_DC_PIN 2

//Touch
#define TOUCH_CS_PIN 32
#define TOUCH_DO_PIN 19
#define TOUCH_IRQ_PIN 27

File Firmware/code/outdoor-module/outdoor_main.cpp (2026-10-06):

#include <Arduino.h>
#include <Wire.h>
#include <WiFi.h>
#include <esp_now.h>

#include <Adafruit_BME280.h>
#include <BH1750.h>

#include "config.h"
#include "../data_n_func.h"


Adafruit_BME280 bme;
BH1750 lightMeter;
OutdoorData outdoorValues;

uint8_t indoorAddress[]={
    //outdoor module's esp32 ADDRESS
}


void OnDataSent(const uint8_t *mac_addr, esp_now_send_status_t status) {
  Serial.print("\r\nLast packet's print status:\t");
  if (status == ESP_NOW_SEND_SUCCESS) {
    Serial.println("Delivery Success");
  }
  else {
    Serial.println("Delivery Failed");
  }




void setup() {
    Serial.begin(115200);
    delay(1000);

    Serial.println("ATMOS CORE!!");
    analogReadResolution(12);

    //bme
    Wire.begin(I2C_SDA_PIN, I2C_SCL_PIN);

    bool bme_success = bme.begin(0x76);
    if(bme_success)
        Serial.println("Successful!");
    else
        Serial.println("Can't find the BME280!");
        return;


    //lightMeter
    bool lightMeter_success = lightMeter.begin();
    if (lightMeter_success)
        Serial.println("Successful!");
    else
        Serial.println("Can't find the lightMeter!");
        return


    pinMode(ANALOG_OUT, INPUT);

    WiFi.mode(WIFI_STA);

    if(esp_now_init() ==  ESP_OK){
        Serial.println("Successful!");
    }
    else{
        Serial.println("Failed to initialize ESP-NOW!");
        return
    }

    esp_now_register_send_cb(OnDataSent);

    esp_now_peer_info_t indoorInfo = {};
    memcpy(indoorInfo.peer_addr, indoorAddress, 6);

    indoorInfo.channel = 0;
    indoorInfo.encrypt = false;

    //Used to be: esp_now_peer(&indoorInfo)
    if(esp_now_add_peer(&indoorInfo) != ESP_OK){
        Serial.println("failed to add indoor peer!");
    }

    Serial.println("ESP-NOW ready");
    
}



void loop() {

    outdoorValues.temperature = bme280.readTemperature();
    outdoorValues.humidity = bme280.readHumidity();
    outdoorValues.pressure = bme280.readPressure()/100.0F;
    //it measures in Pa, so we convert to hPa


    outdoorValues.light_lux = lightMeter.readLight();
    outdoorValues.isRaining = rainSensor(ANALOG_OUT);

    outdoorValues.bat_volt = analogReadMilliVolts(BATTERY_ADC) * 2.00f / 1000.00f; //because we divided our voltage by 2, 470K resistors each!

    esp_now_send(indoorAddress, (uint8_t *)&outdoorValues, sizeof(outdoorValues));

    delay(5000);
}

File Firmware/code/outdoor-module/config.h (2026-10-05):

#pragma once

#define LDO_PS_SYNC 34
#define BATTERY_ADC 35

#define ANALOG_OUT 32
#define DIGITAL_OUT 33

#define CHRG_STAT_PIN 16
#define STDBY_STAT_PIN 17

#define I2C_SDA_PIN 21
#define I2C_SCL_PIN 22

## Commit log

2026-09-19 Revise journal entries for ESP32 project
    Updated journal entries for project progress on ESP32 weather station, including schematic work and component research.
2026-09-19 update
    Added details about the project and components for the ESP32-powered weather station.
2026-09-21 Update journal with wiring progress and challenges
    Documented the completion of wiring the CH340C to the ESP32 and progress on the USB-C port. Included details about challenges faced and additional research on the TP4056.
2026-09-21 schematic png
2026-09-21 20-sept-updates-journal
    Added details about wiring and components for outdoor and indoor modules, including decoupling capacitors, a schottky diode, and updates on the indoor-module schematic.
2026-09-27 Update journal with PCB and case design progress
    Documented the completion of PCB parts placement, addition of a radar sensor, and updates to the case design.
2026-09-27 Document PCB work and case redesign in journal
    Updated journal entry with details on PCB component placement, radar module addition, and case redesign.
2026-09-27 26th september journal
    Documented progress and mistakes in component placement and wiring for the project on 26th September.
2026-09-28 27th sept journal
    Documented progress on indoor and outdoor module PCBs, including component placements and fixes.
2026-09-28 readme update
    Added a radar sensor feature to the indoor module and updated the README to reflect this change.
2026-09-28 readme
    Updated image reference for 3D PCB in README.
2026-09-28 readme
    Updated image path for 3D PCB in README.
2026-09-28 readme
    Correct the image path for the 3D PCB in the README.
2026-09-28 readme.. it's the img
    Corrected the image path for the 3D PCB in the README.
2026-10-02 Update journal with PCB design completion details
    Added update about battery percentage sensing for both PCBs.
2026-10-03 2nd october journal
    Added details about the completion of the outdoor module and battery measurement voltage dividers.
2026-10-03 Add journal entry for CAD work on indoor module
    Documented progress on CAD design for indoor module, including collaboration with teammate and design choices.
2026-10-03 Update CAD journal entry for indoor module design
    Revised the journal entry for CAD work on the indoor module, detailing the design process and collaboration with a teammate.
2026-10-03 2nd october evenign journal
    Expanded journal entry for October 2nd, detailing progress on the outdoor module and CAD work for the indoor module.
2026-10-03 images and timelapses
    Added images and timelapse links for battery measurement and CAD work on indoor module.
2026-10-03 change
    Updated image filename for battery measurement and added additional timelapse links.
2026-10-04 Finalize CAD for indoor module assembly
    Completed CAD and assembly for the indoor module, made adjustments for PCB and TFT display alignment, and ensured radar module positioning.
2026-10-05 consolidating from all the header files into just 3! - also pushing code cuz there's been a lot of back and forth cahnging code! We moved from espidf to arduino!
2026-10-05 3rd october journal
    Document progress on CAD for indoor module and adjustments made to accommodate radar. Include images of completed designs.
2026-10-06 Uploaded Files!!
    [BOM_AtmosCore-Indoor_AtmosCore-Indoor-PCB.csv, BOM_AtmosCore-Outdoor_AtmosCore-Outdoor-PCB.csv, Indoor-Bottom.step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]
2026-10-08 Also put BOM files in main page for east access!!
    [Indoor-Module-BOM.csv, Outdoor-Module-BOM.csv]
